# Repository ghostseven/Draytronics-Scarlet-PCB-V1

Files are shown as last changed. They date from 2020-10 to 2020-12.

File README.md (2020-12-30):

# Draytronics-Scarlet-PCB-V1

dscarlet  

A open source 17 key numpad keyboard, designed to be easily built at home with through hole components. More info / kits / PCB designs available at https://www.draytronics.co.uk/scarlet 

scarlet

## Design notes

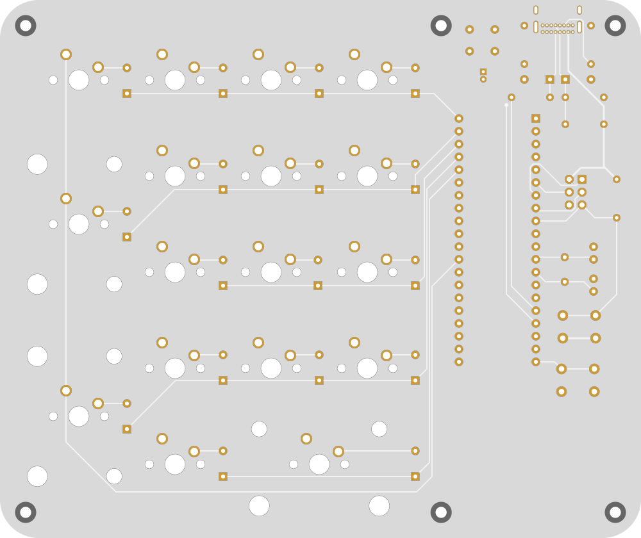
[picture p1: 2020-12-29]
draytronics-scarlet-v1-bottom.png

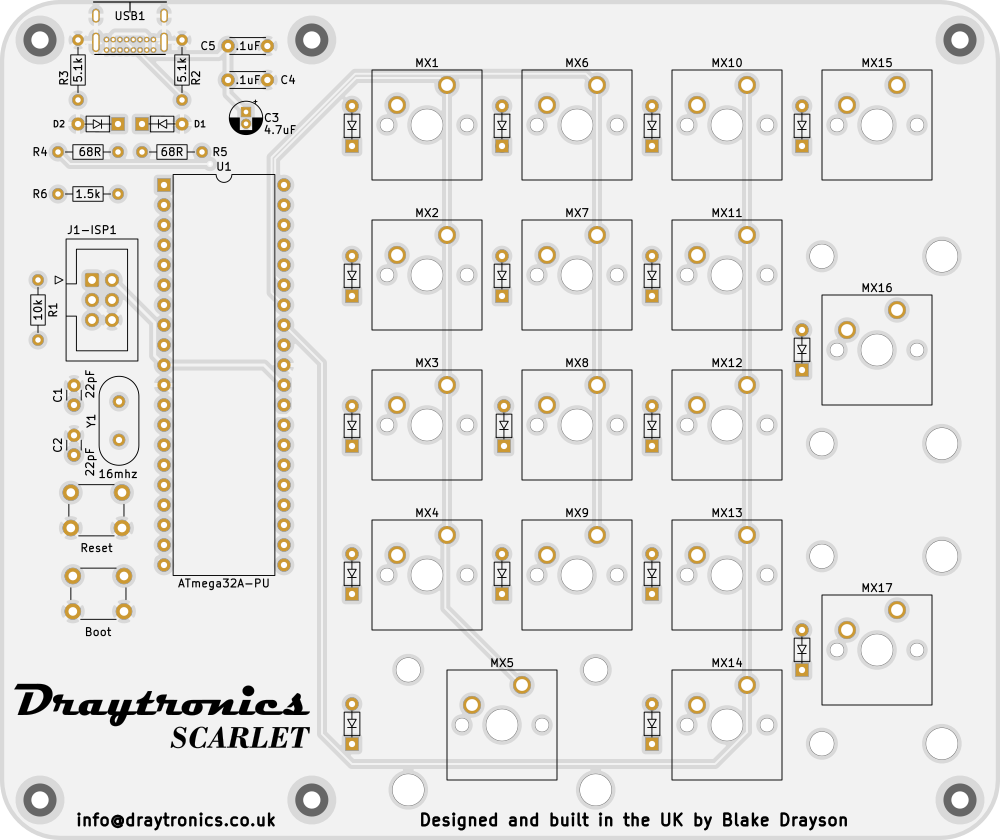
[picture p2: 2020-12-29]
draytronics-scarlet-v1-.png

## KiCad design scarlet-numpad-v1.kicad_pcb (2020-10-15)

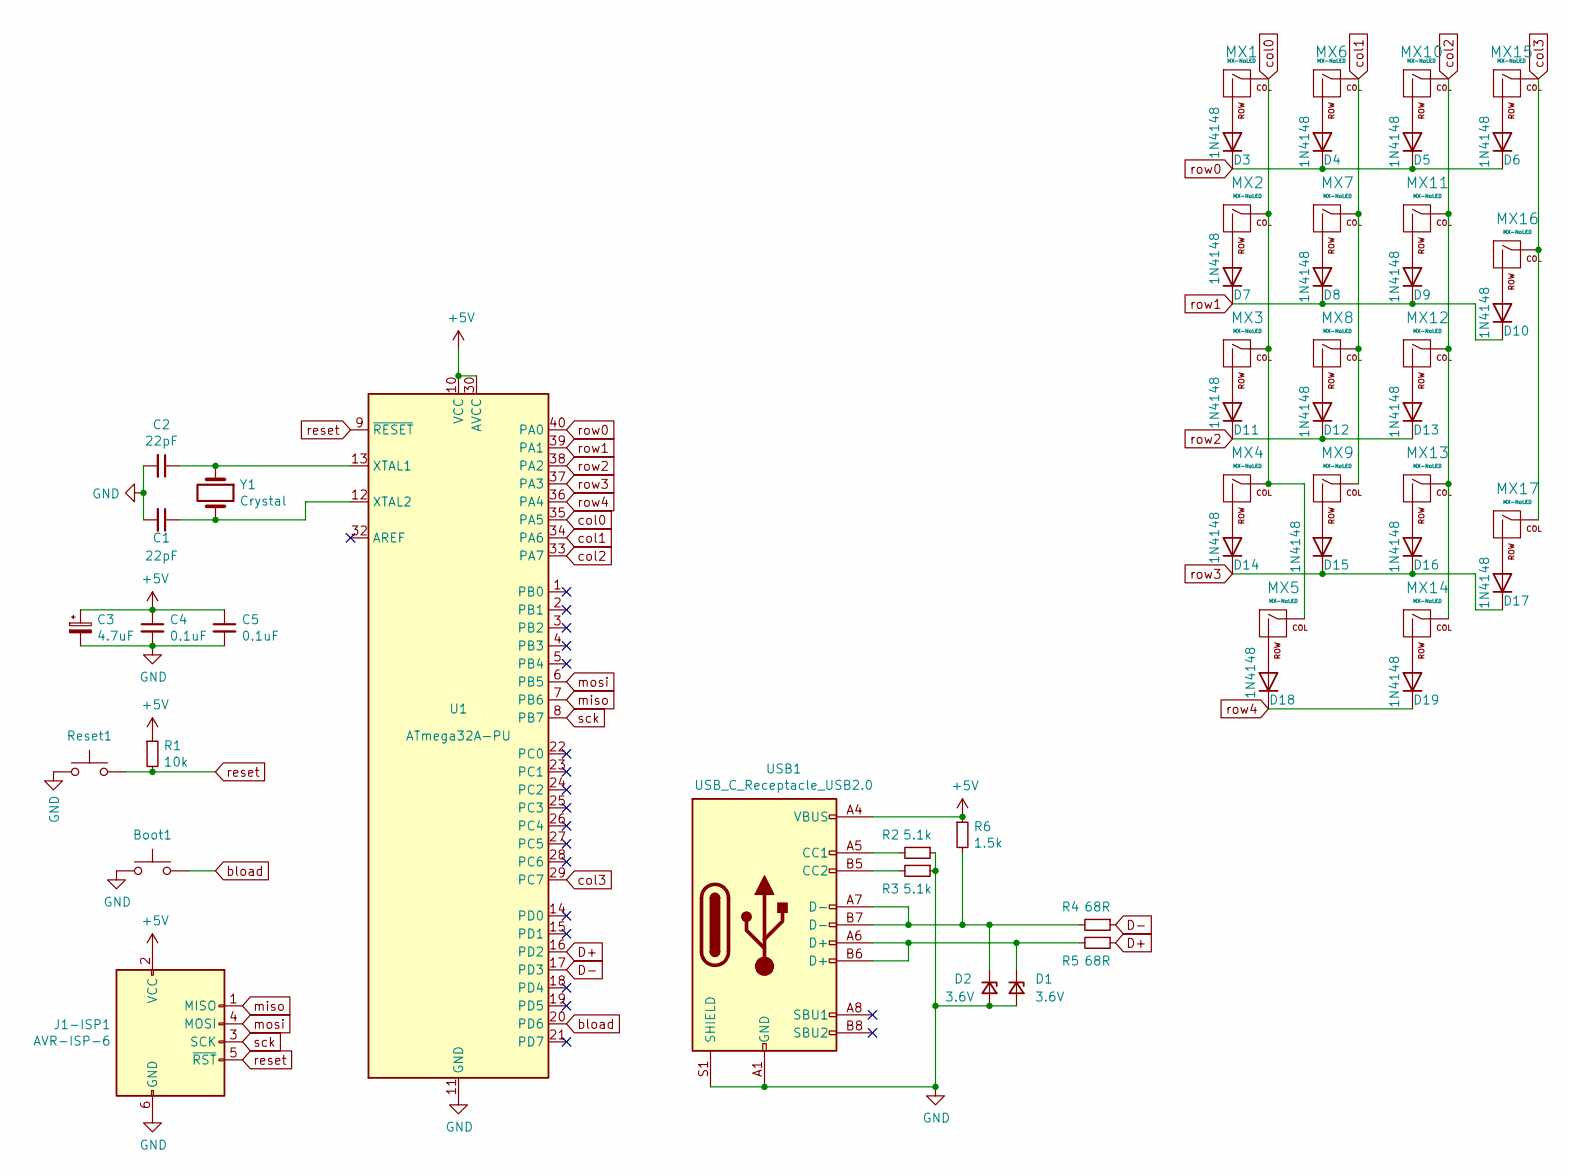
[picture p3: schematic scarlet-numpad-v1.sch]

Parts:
Boot1: Bootloader; SW_PUSH_6mm
C1, C2: 22pF; C_Disc_D3.0mm_W1.6mm_P2.50mm
C3: 4.7uF; CP_Radial_D4.0mm_P1.50mm
C4, C5: 0.1uF; C_Disc_D4.3mm_W1.9mm_P5.00mm
D1, D2: 3.6V; D_DO-35_SOD27_P5.08mm_Horizontal
D3, D4, D5, D6, D7, D8, D9, D10, D11, D12, D13, D14, D15, D16, D17, D18, D19: 1N4148; D_DO-35_SOD27_P5.08mm_Horizontal
J1-ISP1: AVR-ISP-6; IDC-Header_2x03_P2.54mm_Vertical
MX1, MX2, MX3, MX4, MX6, MX7, MX8, MX9, MX10, MX11, MX12, MX13, MX14, MX15: MX-NoLED; SW_Cherry_MX_1.00u_PCB
MX5: MX-NoLED; SW_Cherry_MX_2.00u_PCB
MX16, MX17: MX-NoLED; SW_Cherry_MX_2.00u_Vertical_PCB
R1: 10k; R_Axial_DIN0204_L3.6mm_D1.6mm_P7.62mm_Horizontal
R2, R3: 5.1k; R_Axial_DIN0204_L3.6mm_D1.6mm_P7.62mm_Horizontal
R4, R5: 68R; R_Axial_DIN0204_L3.6mm_D1.6mm_P7.62mm_Horizontal
R6: 1.5k; R_Axial_DIN0204_L3.6mm_D1.6mm_P7.62mm_Horizontal
Reset1: Reset; SW_PUSH_6mm
U1: ATmega32A-PU; DIP-40_W15.24mm
USB1: USB_C_Receptacle_USB2.0; USB_C_GCT_USB4085
Y1: Crystal; Crystal_HC49-U_Vertical

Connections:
+5V: C3.1, C4.1, C5.1, J1-ISP1.2 (VCC), R1.1, R6.1, U1.10 (VCC), U1.30 (AVCC), USB1.A4 (VBUS), USB1.A9 (VBUS), USB1.B4 (VBUS), USB1.B9 (VBUS)
D+: R5.1, U1.16 (PD2)
D-: R4.1, U1.17 (PD3)
GND: Boot1.1, C1.2, C2.2, C3.2, C4.2, C5.2, D1.2 (A), D2.2 (A), J1-ISP1.6 (GND), R2.1, R3.1, Reset1.1, U1.11 (GND), U1.31 (GND), USB1.A1 (GND), USB1.A12 (GND), USB1.B1 (GND), USB1.B12 (GND), USB1.S1 (SHIELD); also elsewhere on the board
unnamed: C1.1, U1.12 (XTAL2), Y1.2
unnamed: C2.1, U1.13 (XTAL1), Y1.1
unnamed: D1.1 (K), R5.2, USB1.A6 (D+), USB1.B6 (D+)
unnamed: D2.1 (K), R4.2, R6.2, USB1.A7 (D-), USB1.B7 (D-)
unnamed: D3.2 (A), MX1.2 (ROW)
unnamed: D4.2 (A), MX6.2 (ROW)
unnamed: D5.2 (A), MX10.2 (ROW)
unnamed: D6.2 (A), MX15.2 (ROW)
unnamed: D7.2 (A), MX2.2 (ROW)
unnamed: D8.2 (A), MX7.2 (ROW)
unnamed: D9.2 (A), MX11.2 (ROW)
unnamed: D10.2 (A), MX16.2 (ROW)
unnamed: D11.2 (A), MX3.2 (ROW)
unnamed: D12.2 (A), MX8.2 (ROW)
unnamed: D13.2 (A), MX12.2 (ROW)
unnamed: D14.2 (A), MX4.2 (ROW)
unnamed: D15.2 (A), MX9.2 (ROW)
unnamed: D16.2 (A), MX13.2 (ROW)
unnamed: D17.2 (A), MX17.2 (ROW)
unnamed: D18.2 (A), MX5.2 (ROW)
unnamed: D19.2 (A), MX14.2 (ROW)
unnamed: R2.2, USB1.A5 (CC1)
unnamed: R3.2, USB1.B5 (CC2)
bload: Boot1.2, U1.20 (PD6); also elsewhere on the board
col0: MX1.1 (COL), MX2.1 (COL), MX3.1 (COL), MX4.1 (COL), MX5.1 (COL), U1.35 (PA5)
col1: MX6.1 (COL), MX7.1 (COL), MX8.1 (COL), MX9.1 (COL), U1.34 (PA6)
col2: MX10.1 (COL), MX11.1 (COL), MX12.1 (COL), MX13.1 (COL), MX14.1 (COL), U1.33 (PA7)
col3: MX15.1 (COL), MX16.1 (COL), MX17.1 (COL), U1.29 (PC7)
miso: J1-ISP1.1 (MISO), U1.7 (PB6)
mosi: J1-ISP1.4 (MOSI), U1.6 (PB5)
reset: J1-ISP1.5 (~RST), R1.2, Reset1.2, U1.9 (~RESET); also elsewhere on the board
row0: D3.1 (K), D4.1 (K), D5.1 (K), D6.1 (K), U1.40 (PA0)
row1: D7.1 (K), D8.1 (K), D9.1 (K), D10.1 (K), U1.39 (PA1)
row2: D11.1 (K), D12.1 (K), D13.1 (K), U1.38 (PA2)
row3: D14.1 (K), D15.1 (K), D16.1 (K), D17.1 (K), U1.37 (PA3)
row4: D18.1 (K), D19.1 (K), U1.36 (PA4)
sck: J1-ISP1.3 (SCK), U1.8 (PB7)

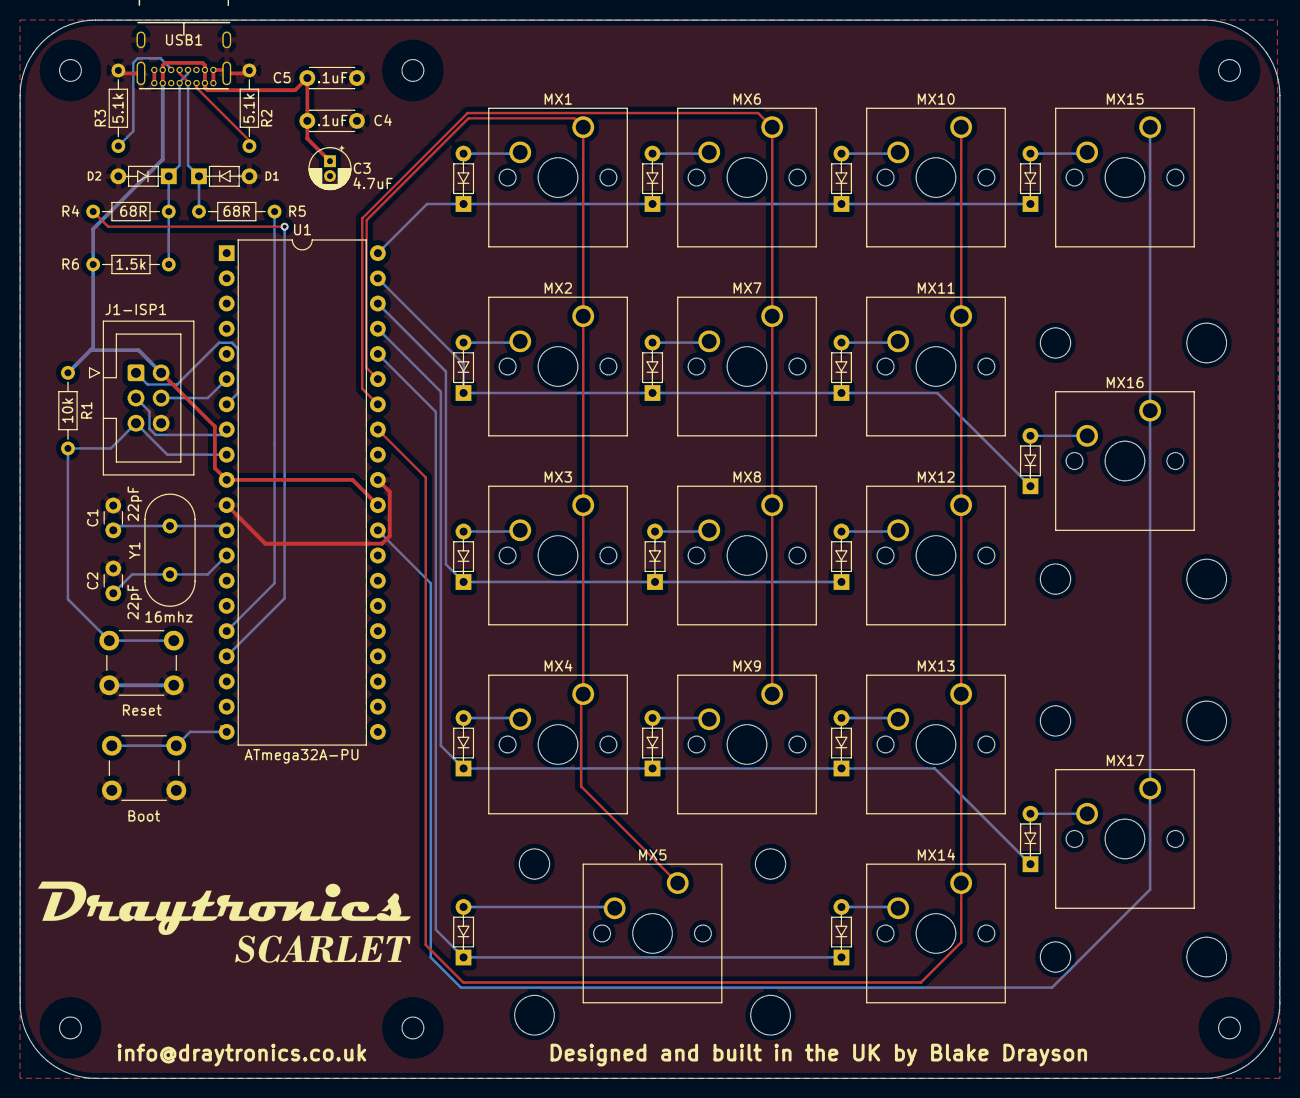
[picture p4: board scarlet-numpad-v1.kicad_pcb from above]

Board: 2 copper layers, 127.0 x 106.7 mm, 53 parts (0 on the bottom side), 41 nets.

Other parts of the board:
Boot: Bootloader; SW_PUSH_6mm
Reset: Reset; SW_PUSH_6mm

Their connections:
GND: Boot.1, Reset.1; also elsewhere on the board
bload: Boot.2; also elsewhere on the board
reset: Reset.2; also elsewhere on the board

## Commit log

2020-11-15 Added laser cutting files for acrylic case
2020-12-29 Added PCB renders
